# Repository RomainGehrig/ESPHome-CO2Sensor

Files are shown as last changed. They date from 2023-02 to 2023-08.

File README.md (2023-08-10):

# DIY CO2 sensor with a printable case

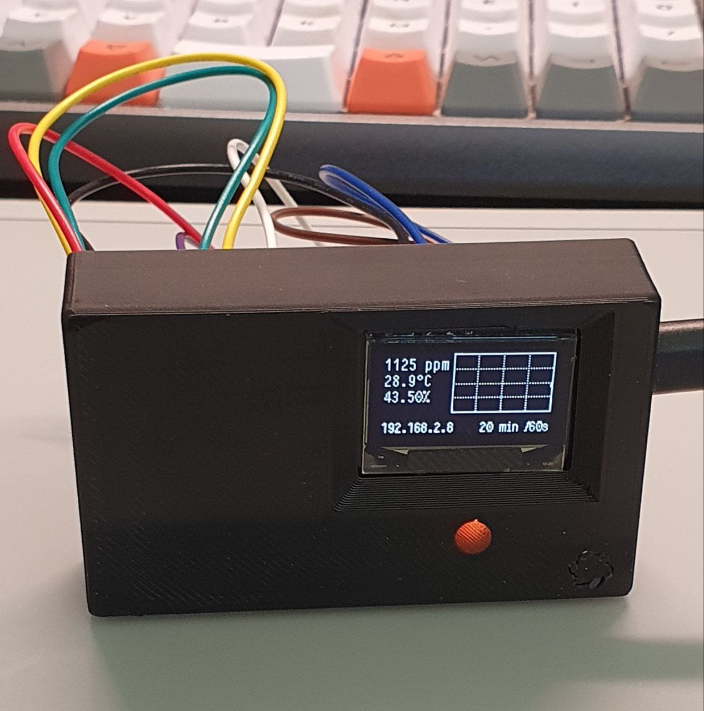
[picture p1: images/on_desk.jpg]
 

Features:
- Measures CO2, temperature and humidity every 60 seconds
- Displays a graph with the CO2 values of the last 20 min / 2 hours 
- The RGB LED indicates current CO2 levels: green at 500ppm to red for 1800ppm
- A button with two actions: one short click to switch between 20min and 2h graphs, on long click to start a 10-min "fast polling" period (one measure every 5 seconds)
- Can be easily added to Home Assistant using the ESPHome integration: the device's IP address is on the screen

Hardware needed:
- ESP32 board: Wemos Lolin32 OLED (128x64px, uses SSD1306 on i2c)
- CO2 sensor: SCD40 by Sensirion
- RGB LED: a WS2812 breakout board (had to use neopixelbus platform as I encountered problems with fastled)
- A tactile switch (6x6x5mm) with two legs
- Some M3 screws if housing the device in the printed case

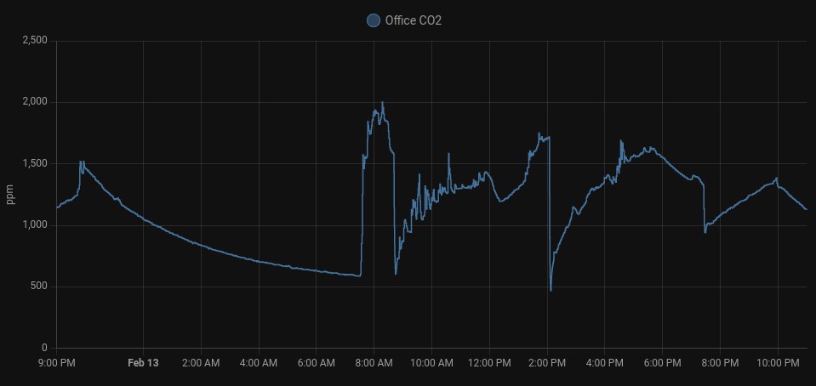
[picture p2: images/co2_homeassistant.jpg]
 

## Connecting the components

I'm using jumper wires but when my protoboards arrive I'll solder some headers and wire the board properly. With the headers, it will still be easy to pull components to use them in other projects.

**Wemos Lolin32 pinout:**
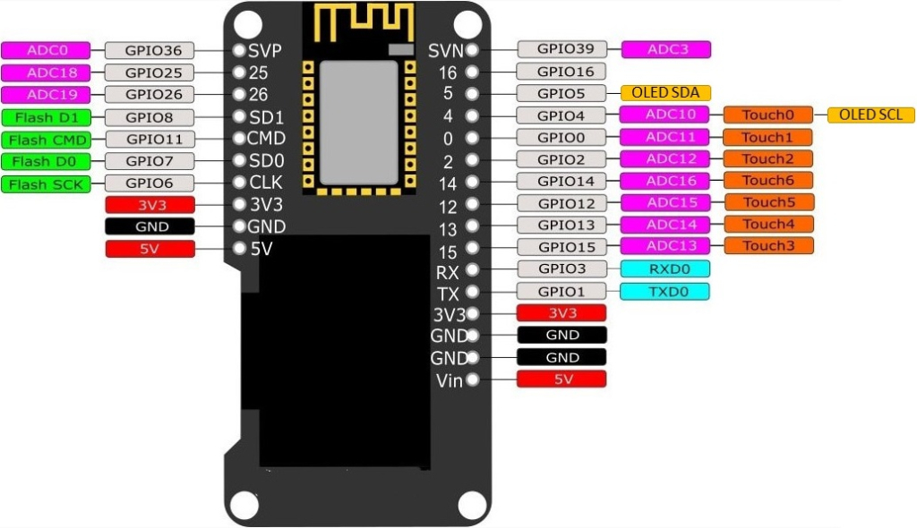
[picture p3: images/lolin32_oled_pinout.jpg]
 
Source: [Wemos Lolin32 schematic](https://randomnerdtutorials.com/esp32-built-in-oled-ssd1306/)

Connections:
- i2c uses pins 4 (SCL) and 5 (SDA) for the display so the SCD40 needs to use those pins too
- SCD40 has a 2.4 - 5.5V supply voltage range (see [see datasheet](https://cdn.sparkfun.com/assets/d/4/9/a/d/Sensirion_CO2_Sensors_SCD4x_Datasheet.pdf)) so either 3.3V or 5V is fine
- The LED uses pin 2 for data, and 5V for power
- I put the button between 5V and GPIO25

## ESPHome config 

For installation of ESPHome, I'll let you refer to the [ESPHome doc](https://esphome.io/).

**Secrets**: to upload the `CO2Sensor.yaml` config to your board, you'll need a `secrets.yaml` file with WiFi credentials and OTA password – look at `secrets.example.yaml` for an example. 

**Fonts**: I use PragmataPro because it is nice and legible on a small display, but I can't share it due for licensing reasons. You either have to get it yourself and put it the `fonts` directory of your ESPHome directory, or [look at the ESPHome doc to change the `font:` section](https://esphome.io/components/display/index.html#fonts).

## Case

I wanted a printable case to house the device more cleanly than on a breadboard.

Design goals:
 - Able to hang on the wall
 - Printable without support
 - The CO2 sensor (SCD40) gets fresh air and is isolated from other components
 - Expensive components must be reusable in other projects: so no gluing and no soldering
 - Minimal footprint

I ended up with this design:
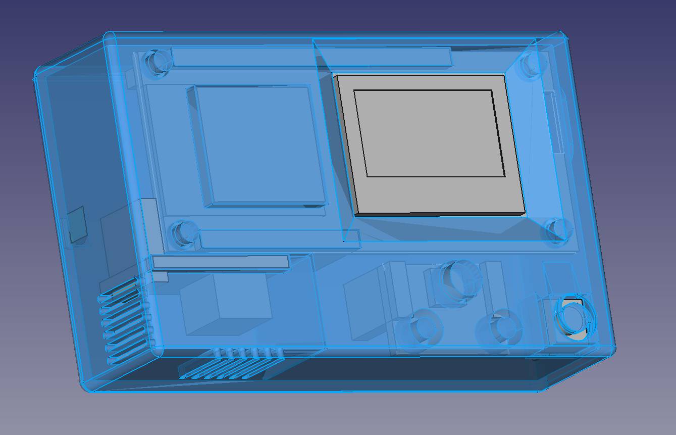
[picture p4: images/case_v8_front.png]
 
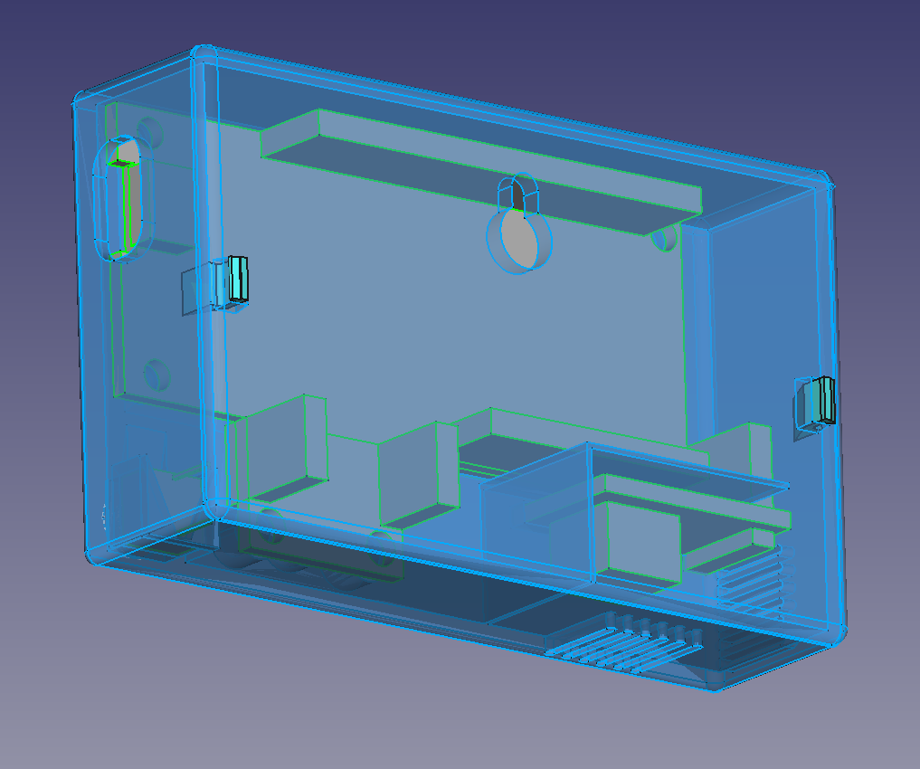
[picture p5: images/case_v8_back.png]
 

The current version of the case is available in STL or Step files in this repo.

### Printing the case

I printed my case face down with black PLA, a 0.4mm nozzle, 0.15mm layer height, 10% infill, using **arachne** wall generation for the button cover. After slicing, verify that the button cover looks printable at layers 1-3. You shouldn't need support for any part.

As I don't have short M3 screws, I created 2mm/5mm spacers to accommodate longer ones.

### Housing the components into the case

Need at least two M3 screws, and use 2mm/5mm spacers as needed if they are too long.

1. Slide button with two legs into position (using some tweezers if needed)
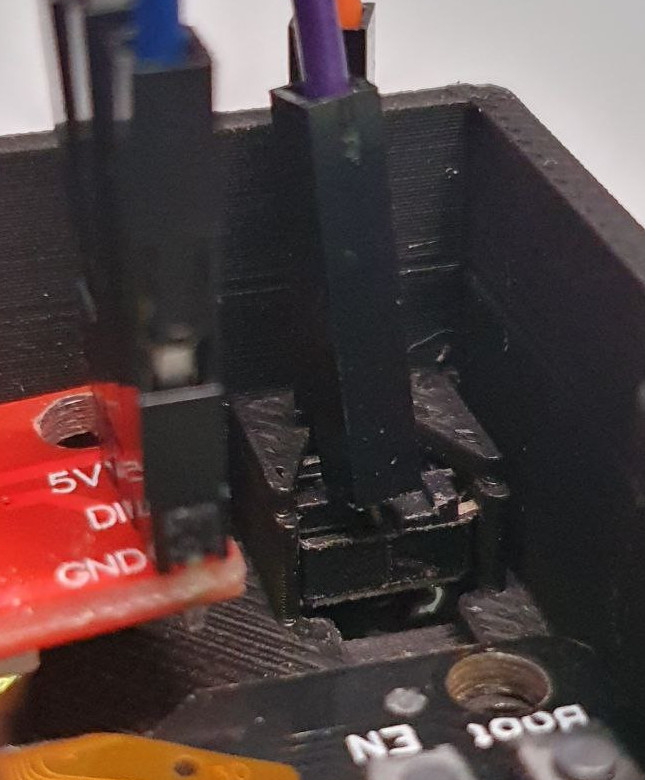
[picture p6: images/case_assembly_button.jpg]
 
2. Ease the plastic button cover on the front of the case by actuating it a few times with a round tip. Make sure the button is still behind, or you could break the cover.
3. Before placing more components, note how the different wires are connected to the Wemos as its pins are not marked underneath! 
4. Screw in the Wemos Lolin32, putting at least one screw near the USB. 
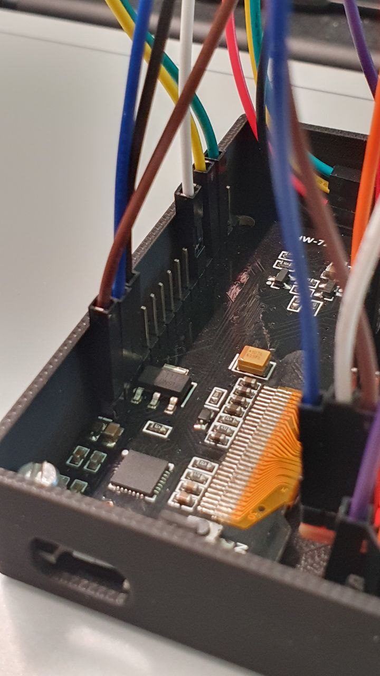
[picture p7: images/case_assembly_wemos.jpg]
 
5. Screw in the LED – preferably with two screws but you may get away with one.
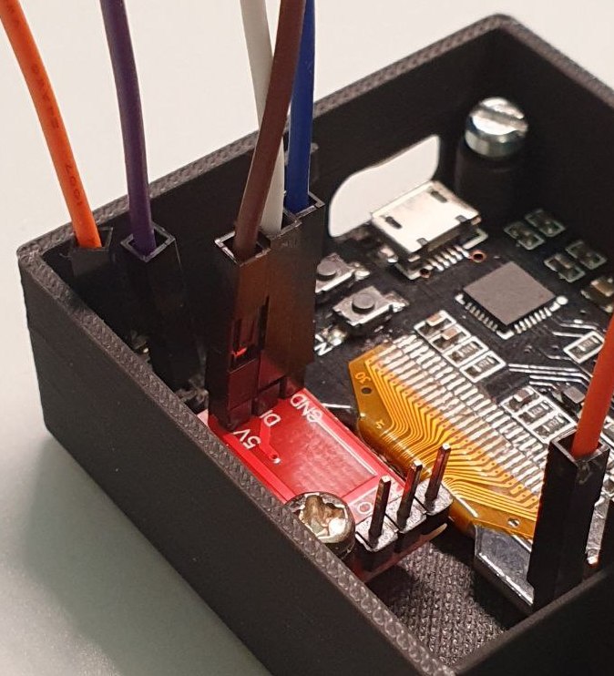
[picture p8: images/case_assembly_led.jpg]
 
6. Slide the SCD40 vertically into its slot on the bottom right of the case. I added some tolerance so it may be a bit loose. In this case, you can put a tiny piece of double sided tape between the vertical wall and the PCB.
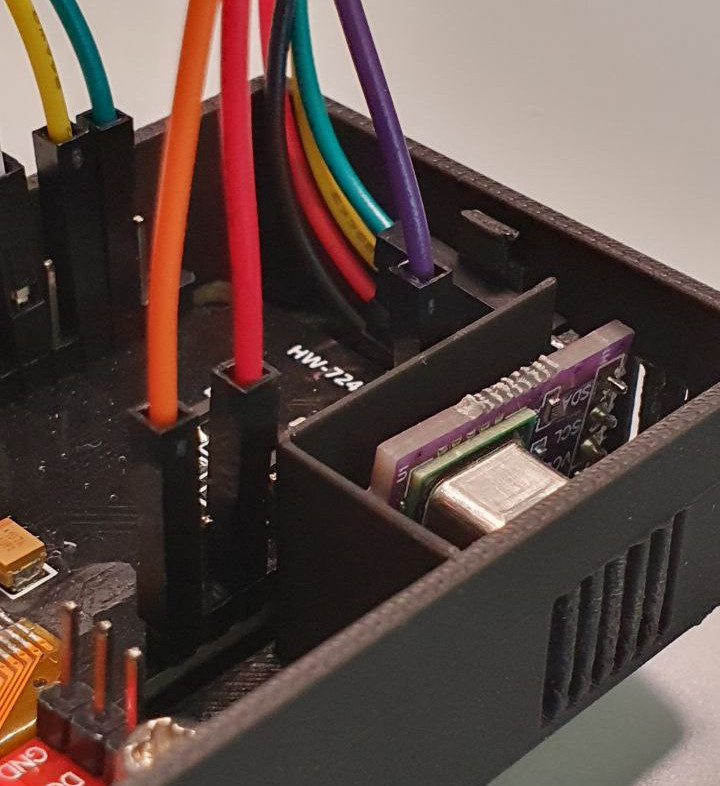
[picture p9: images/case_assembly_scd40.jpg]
 
7. Verify that all wires are connected to where they should be and you're done!

### Result

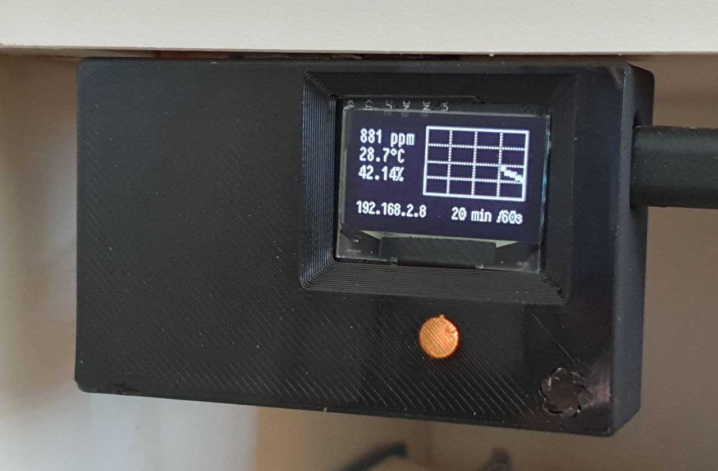
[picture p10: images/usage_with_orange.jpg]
 
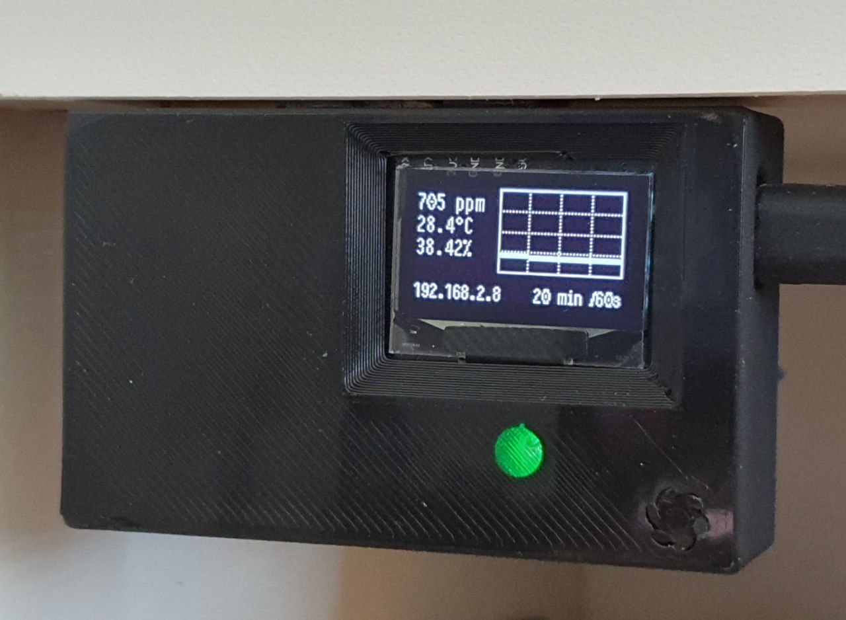
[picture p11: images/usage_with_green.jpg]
 

## Thanks

Many thanks to the [Fablab Renens](https://fablab-renens.ch/) and [FIXME](https://fixme.ch/) for organizing and hosting the [Capte Ton CO2 workshop](https://fixme.ch/node/220) that started my ESP32 and ESPHome journey!

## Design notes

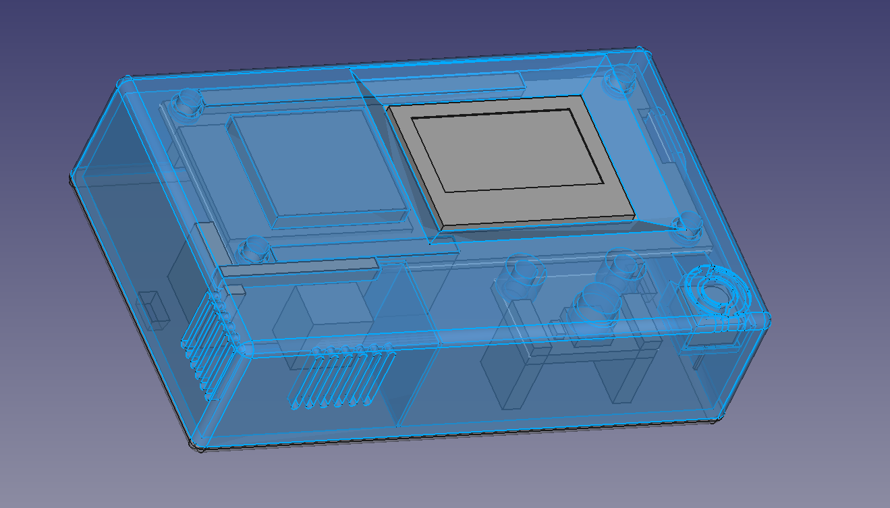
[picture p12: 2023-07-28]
images/case_v4.png

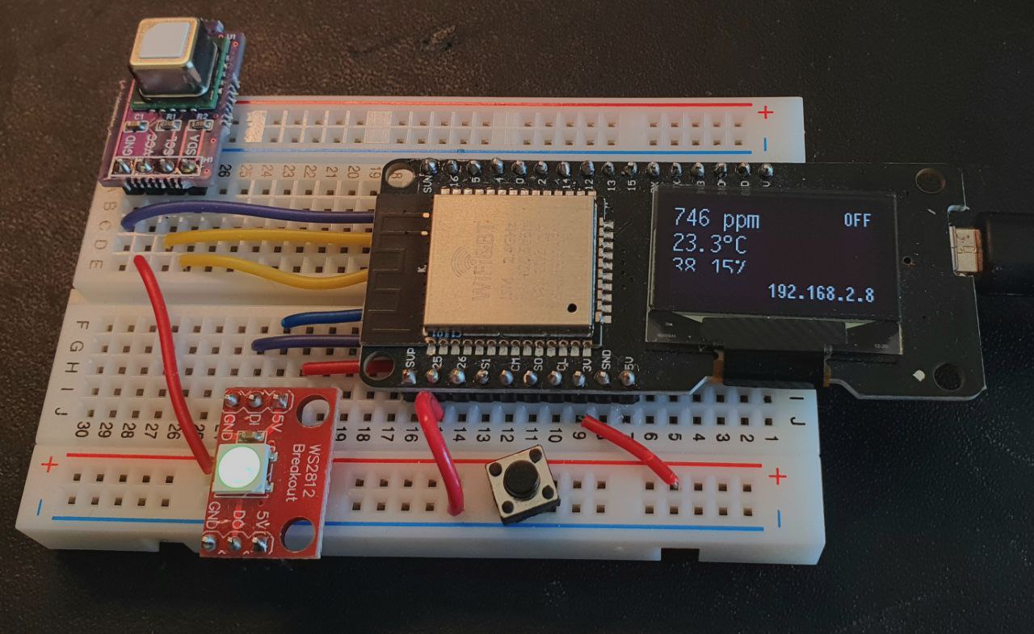
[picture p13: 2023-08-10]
images/co2_green.jpg

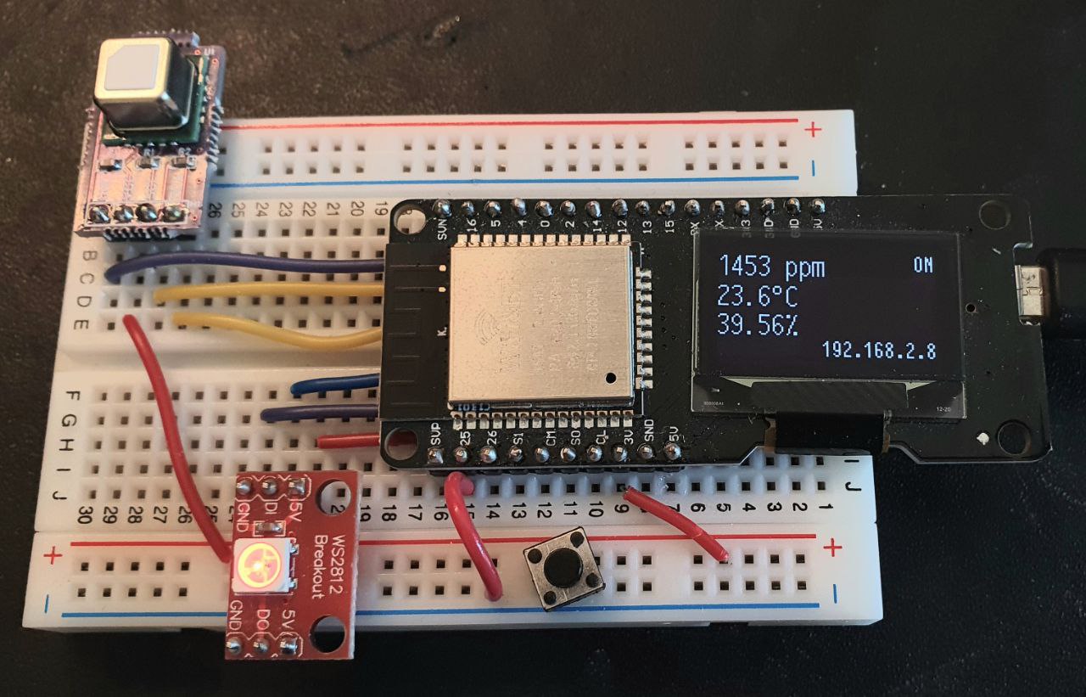
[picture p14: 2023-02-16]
images/co2_red.jpg

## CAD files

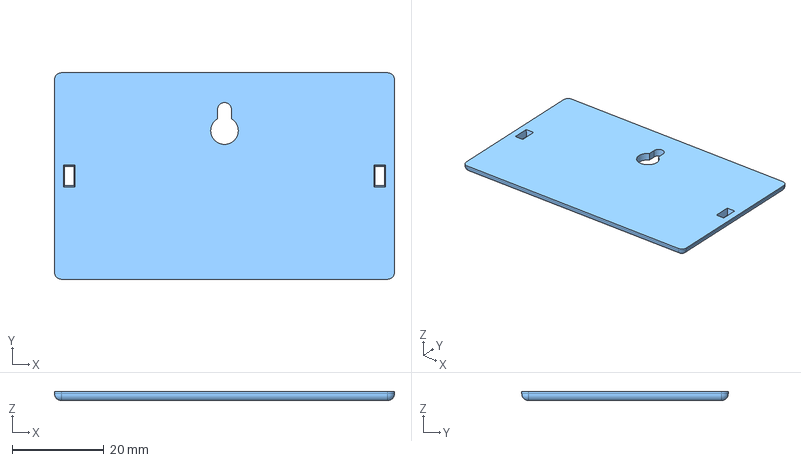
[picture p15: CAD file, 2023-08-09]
case/Step/Backplate.step
74.0 x 45.0 x 2.00 mm

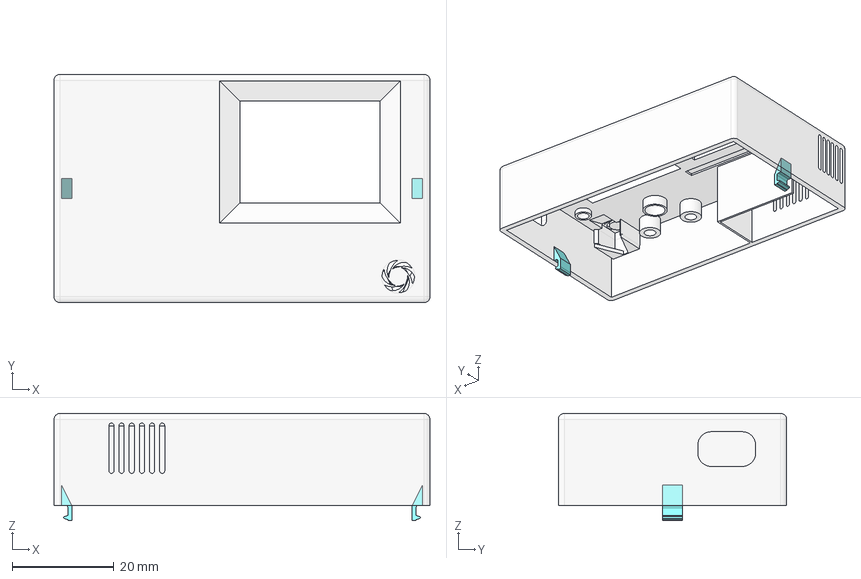
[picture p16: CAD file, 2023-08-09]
case/Step/Case.step
74.0 x 45.0 x 21.1 mm
Case
MaleClip001 x 2

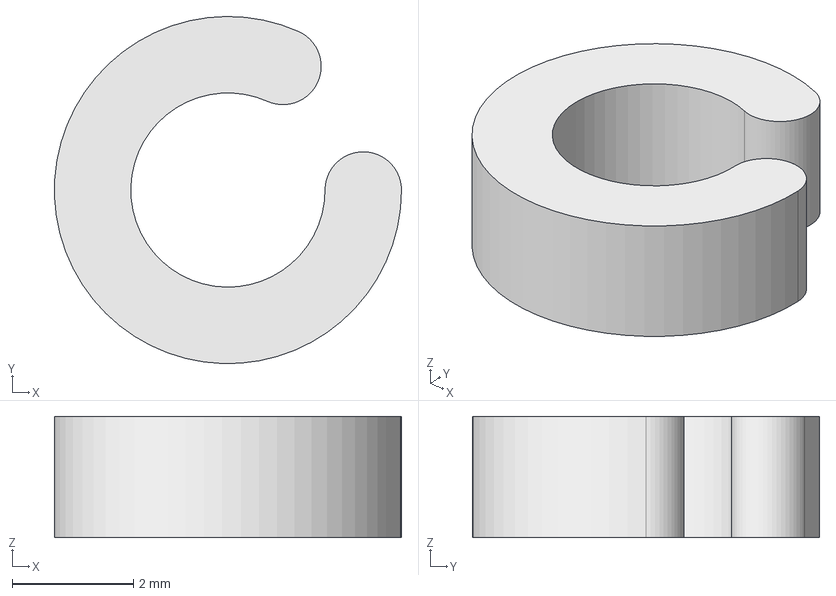
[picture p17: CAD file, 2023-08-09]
case/Step/ScrewSpacer-2mm.step
5.72 x 5.72 x 2.00 mm

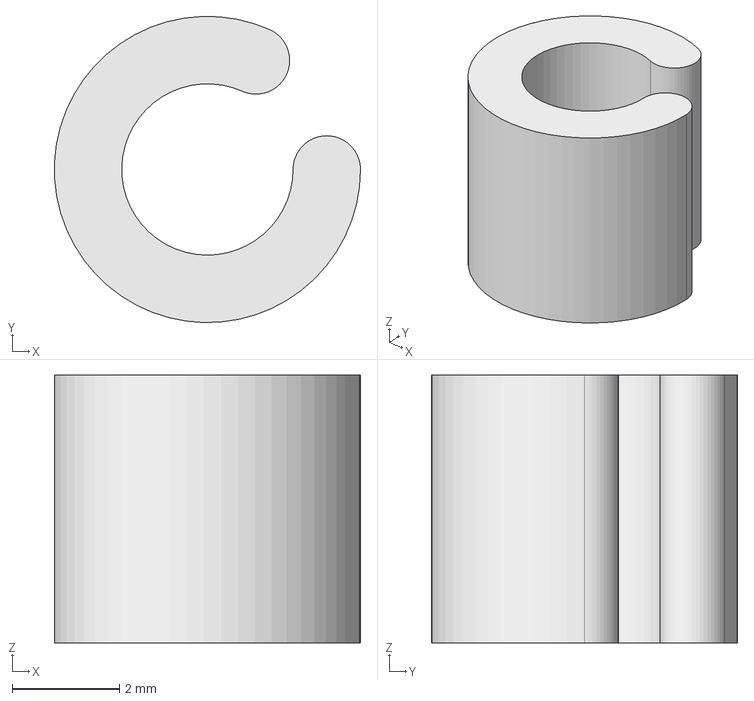
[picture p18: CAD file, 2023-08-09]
case/Step/ScrewSpacer-5mm.step
5.72 x 5.72 x 5.00 mm

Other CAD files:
case/STL/Backplate.stl
case/STL/Case.stl
case/STL/ScrewSpacer-2mm.stl
case/STL/ScrewSpacer-5mm.stl

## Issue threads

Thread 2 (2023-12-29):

STL files not being recognized correctly by online 3D print services

osamaamin33, 2023-12-29:

osamaamin33, 2023-12-29:
I tried the files from printables.com  and they seems to be work fine. So probably some issue in the git repo files.

RomainGehrig, 2023-12-30:
Thanks for the report! The files should be the same on both Printables and Github. Which files and online print services don't work?

osamaamin33, 2024-01-05:
sorry for the late reply. i tried some online printing services like https://i.materialise.com/en and the files i donwloaded from github were not able to work. But the files from printables which you uploaded for the same project worked fine.

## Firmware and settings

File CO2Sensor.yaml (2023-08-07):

esphome:
  name: co2sensor

esp32:
  board: lolin32
  framework:
    type: arduino

api:
  port: 6053
  reboot_timeout: 0s

wifi:
  ssid: !secret wifi_ssid
  password: !secret wifi_password
  fast_connect: true
  reboot_timeout: 0s

ota:
  safe_mode: true
  password: !secret ota_password

font:
  - file: 'fonts/PragmataPro.ttf'
    id: font1
    size: 16

  - file: 'fonts/PragmataPro.ttf'
    id: font_small
    size: 12

  - file: 'fonts/PragmataPro.ttf'
    id: font_tiny
    size: 10

i2c:
  sda: 5
  scl: 4

switch:
  - platform: template
    id: hourly_graph
    name: "Hourly graph"
    optimistic: true
  - platform: template
    id: fast_poll_on
    name: "Fast polling"
    optimistic: true


display:
  - platform: ssd1306_i2c
    model: "SSD1306 128x64"
    address: 0x3C
    id: screen
    pages:
      - lambda: |-
          if (id(co2).has_state()) {
            it.printf(0, 13, id(font_small), TextAlign::BASELINE_LEFT , "%.0f ppm", id(co2).state);
          }

          if (id(temperature).has_state()) {
            it.printf(0, 26, id(font_small), TextAlign::BASELINE_LEFT , "%.1f°C", id(temperature).state);
          }

          if (id(humidity).has_state()) {
            it.printf(0, 39, id(font_small), TextAlign::BASELINE_LEFT , "%.2f%%", id(humidity).state);
          }

          if (id(ip_address).has_state()) {
            it.printf(0, 64, id(font_tiny), TextAlign::BASELINE_LEFT, "%s", id(ip_address).state.c_str());
          } else {
            it.print(0, 64, id(font_tiny), TextAlign::BASELINE_LEFT, "No WiFi");
          }

          if (id(hourly_graph).state) {
            it.graph(52, 0, id(co2graph));
            it.print(90, 64, id(font_tiny), TextAlign::BASELINE_CENTER, "2h");
          } else {
            it.graph(52, 0, id(co2graph_small));
            it.print(90, 64, id(font_tiny), TextAlign::BASELINE_CENTER, "20 min");
          }

          auto poll_txt = id(fast_poll_on).state ? "/5s": "/60s";
          it.print(128, 64, id(font_tiny), TextAlign::BASELINE_RIGHT, poll_txt);


graph:
  - id: co2graph_small
    sensor: co2
    duration: 20min
    width: 76
    height: 48
    min_value: 400
    max_value: 2000
    y_grid: 400
    x_grid: 5min
    border: true
  - id: co2graph
    sensor: co2
    duration: 2h
    width: 76
    height: 48
    min_value: 400
    max_value: 2000
    y_grid: 400
    x_grid: 15min
    border: true

sensor:
  - platform: scd4x
    id: sdc40
    measurement_mode: periodic
    update_interval: 60s
    co2:
      name: "Office CO2"
      id: "co2"
      on_value:
        then:
          - lambda: |-
              float co2 = std::min(float(1800), x);
              auto t = (co2-440)/(1800 - 440);
              auto interpolated = ESPHSVColor(uint8_t((1-t)*96), 255, 32);
              auto inter_rgb = interpolated.to_rgb();

              auto call = id(co2light).turn_on();
              call.set_rgb(inter_rgb.red / 255.0, inter_rgb.green / 255.0, inter_rgb.blue / 255.0);
              call.set_brightness(0.3);
              call.perform();

    temperature:
      name: "Office Temperature"
      id: "temperature"
    humidity:
      name: "Office Humidity"
      id: "humidity"

interval:
  - interval: 5s
    then:
      - if:
          condition:
            switch.is_on: fast_poll_on
          then:
            - component.update: sdc40

binary_sensor:
  - platform: gpio
    pin:
      number: GPIO25
      mode:
        input: true
        pulldown: true
    id: "btn"
    name: "Breadboard button"
    filters:
      - delayed_on: 10ms
    on_press:
      then:
        - switch.toggle: hourly_graph
    on_click:
      min_length: 750ms
      max_length: 5000ms
      then:
        - switch.turn_on: fast_poll_on
        - delay: 10min
        - switch.turn_off: fast_poll_on

text_sensor:
  - platform: wifi_info
    ip_address:
      name: ESP IP Address
      id: ip_address
    ssid:
      name: ESP Connected SSID
      id: wifi_ssid

light:
  - platform: neopixelbus
    type: GRB
    variant: WS2812
    pin: GPIO2
    num_leds: 1
    name: "CO2 LED"
    id: co2light
    entity_category: diagnostic

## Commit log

2023-03-02 WIP standalone version of the CO2 sensor with a graph display
2023-03-02 Use button to switch between display pages
    Remove fast_poll mode: default is update every 5s
2023-03-03 Use a switch to change the graph, instead of display pages
2023-03-03 ESP no longer reboots after 15min with no connection
    We don't want the default behavior in this case, as we know there won't
    be any connection.
2023-07-28 Add screen of case v4
2023-08-09 Add 3D files for the case
    [Backplate.step, Backplate.stl, Case.step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]
2023-08-10 Update README with instructions for the 3D case
